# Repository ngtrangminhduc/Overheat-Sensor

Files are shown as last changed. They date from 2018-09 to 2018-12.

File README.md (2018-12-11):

# An Overheat Sensor with Raspberry Pi and HDC1008 sensor 

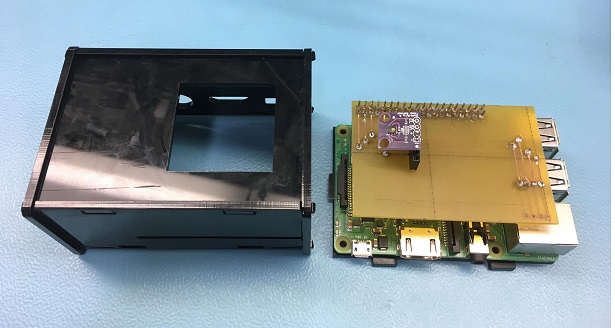
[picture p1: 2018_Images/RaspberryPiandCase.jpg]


## Table of Contents

I. [Introduction](#i-introduction)

II. [Overheat Sensor Materials](#ii-overheat-sensor-materials)

III. [Overheat Sensor Schedule](#iii-overheat-sensor-schedule)

IV. [Overheat Sensor Assembly](#iv-overheat-sensor-assembly)

V. [Overheat Sensor Power Up and Testing](#v-overheat-sensor-power-up-and-testing)

VI. [Image Creation and Enterprise Wifi](#vi-image-creation-and-enterprise-wi-fi)

VII. [Reproduction in Quantity](#vii-reproduction-in-quantity)

### I. Introduction

Raspberry Pi gets overheat easily when combined with other components, and can hardly be noticed if put inside cases. Internal hardware can be damaged if no immediate resolutions are taken.

HDC1008 is a Temperature and Humidity sensor that can solve the problem. It8 has a wide range of temperature with +-0.2 Celsius degree, making it a very accurate sensor to detect any temperature change, and to ensure a spontaneous reaction from the users. Its low power consumption and two operation modes (sleep and measurement) allow itself to fit battery / power harvesting applications.

**Note**: This sensor is now classified as **Obsolete** in most of electronic websites, due to the coming of many new upgraded sensors

The whole operation of the project can be demonstrated through this XML diagram: 

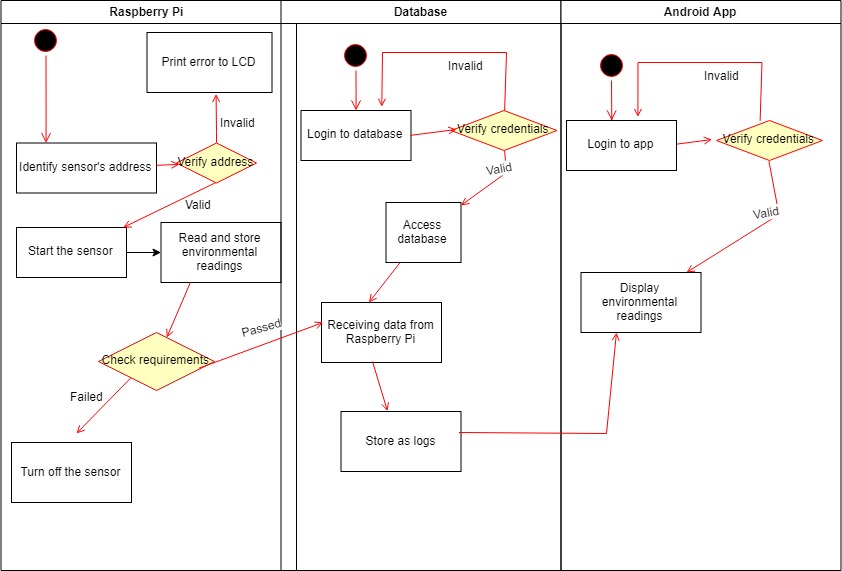
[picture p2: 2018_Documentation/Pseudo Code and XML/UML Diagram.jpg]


For convenient purposes, this documentation will focus mainly on the production of the sensor only. 

### II. Overheat Sensor Materials

The components for this project are:
- Raspberry Pi 3B+
- HDC1008 Temperature & Humidity Sensor  
- PCB
- I2C LED Screen (Optional)
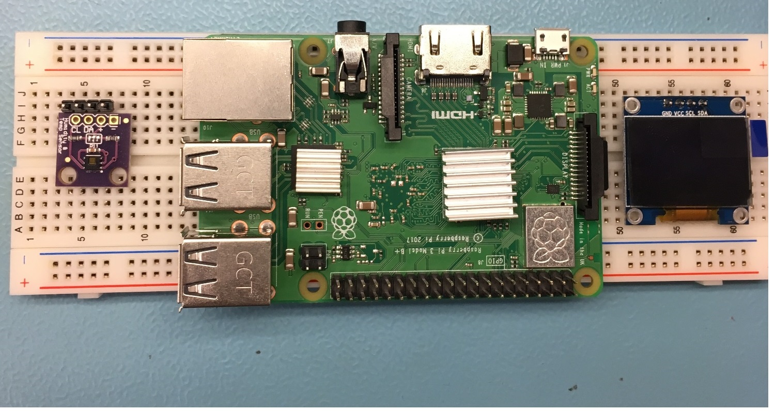
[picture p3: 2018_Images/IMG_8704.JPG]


- 6-pin headers
- 2x20-pin header

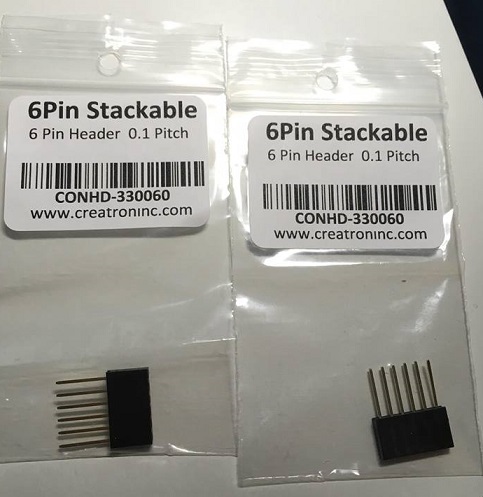
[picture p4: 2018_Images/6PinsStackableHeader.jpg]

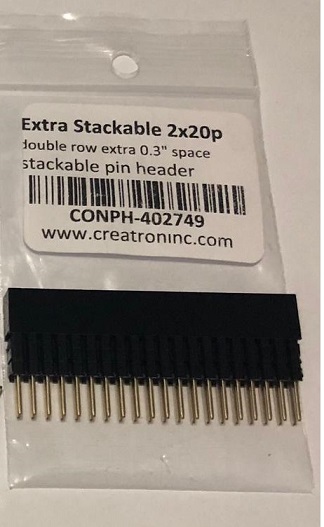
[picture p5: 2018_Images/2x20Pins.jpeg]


The softwares for this project are:
- Remote Desktop Connection / VNC Viewer
- Fritzing (for designing purposes) (can be freely used in the Lab)
- CorelDraw (for designing purposes) (can be freely used in the Lab)

Total budget for this project is approximately 190$. More details can be found in the <a href="https://raw.githubusercontent.com/ngtrangminhduc/OverheatSensor/master/2018_Documentation/Proposal%2C%20Budget%2C%20Project%20Schedule/Budget.xlsx">budget</a>.

The HDC1008 sensor should be ordered as soon as possible, as it may take up 2 weeks to 1 month due to its unpopularity

### III. Overheat Sensor Schedule
Overall, if all materials are present, then it should not take more than 3 days to build a complete, functional product. Most of the time will be spent on installing the SD card and building the case for the Raspberry Pi, while the coding is rather simple.

This is the schedule I followed for the whole semester

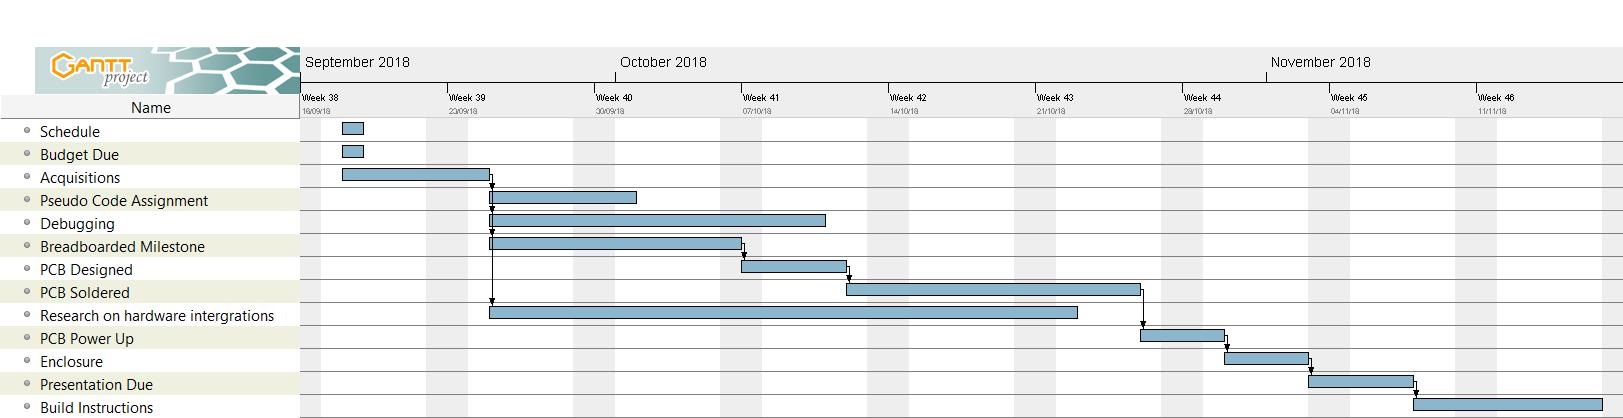
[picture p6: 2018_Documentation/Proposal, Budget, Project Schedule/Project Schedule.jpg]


### IV. Overheat Sensor Assembly

#### IV.1 Printed Circuit Board

A PCB is required to connect the Sensor to the Raspberry Pi without using jumper wires and such. The design file of PCB can be found <a href="https://raw.githubusercontent.com/ngtrangminhduc/OverheatSensor/master/2018_Documentation/Fritzing/DucNguyen_HDC1008.zip">here</a>.
This is the Breadboard view of the project:

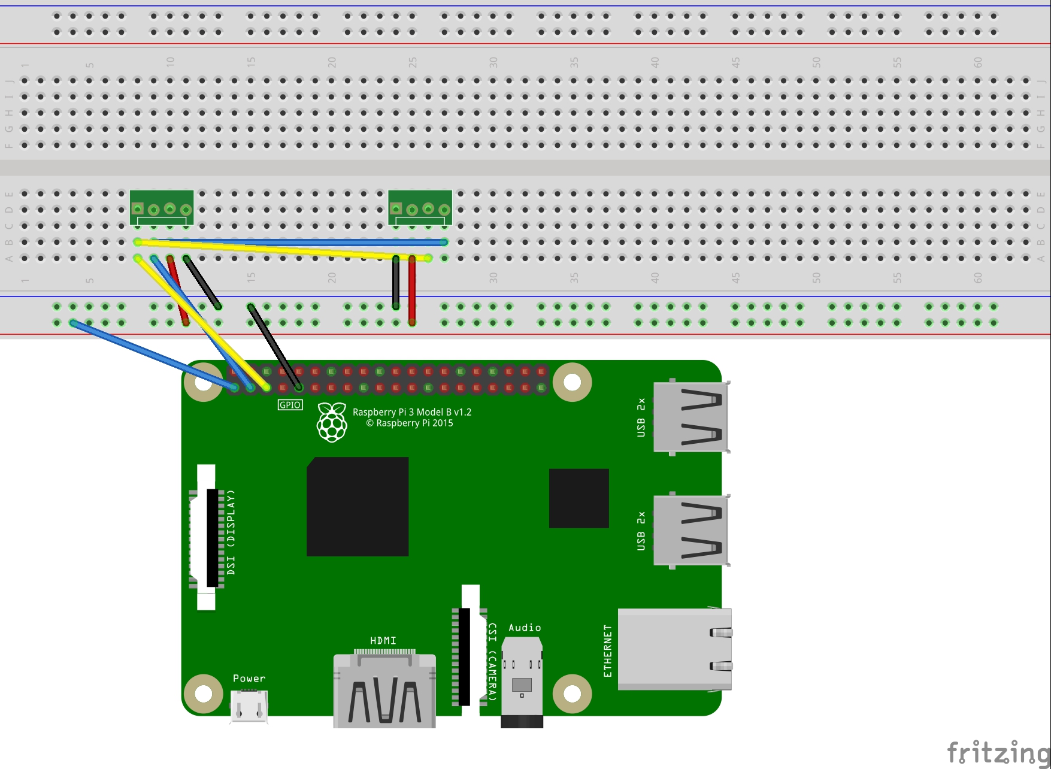
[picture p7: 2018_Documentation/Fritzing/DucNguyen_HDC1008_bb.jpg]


The PCB View was designed, based on the Breadboard View by using Fritzing.

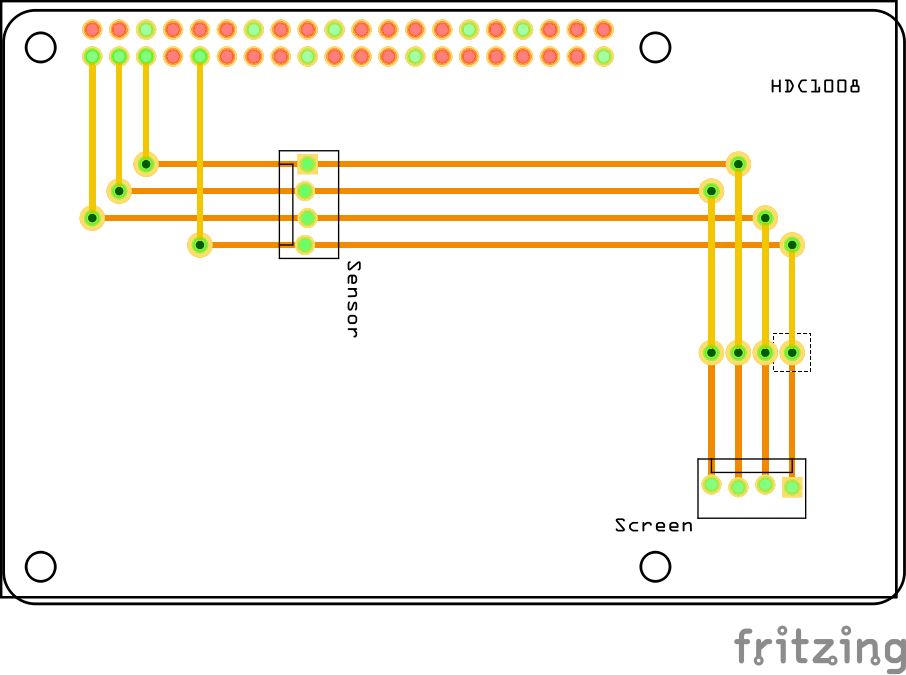
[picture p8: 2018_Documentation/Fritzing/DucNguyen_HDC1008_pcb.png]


Soldering can be done in the Lab, which may take you 30mins to 2hours, depends on how comfortable you are in soldering:

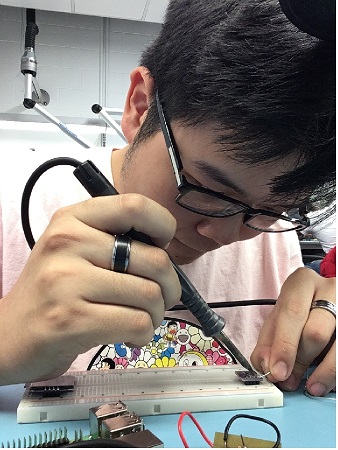
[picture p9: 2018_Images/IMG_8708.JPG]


This is the finished PCB

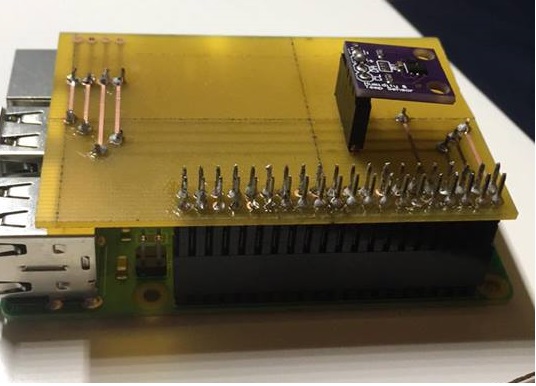
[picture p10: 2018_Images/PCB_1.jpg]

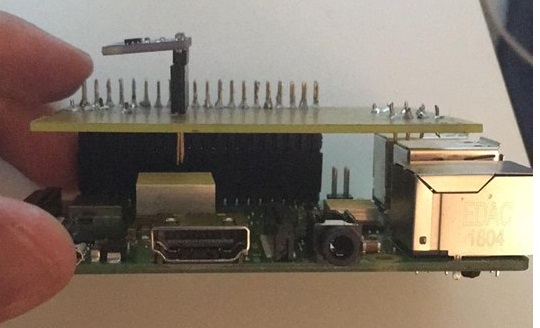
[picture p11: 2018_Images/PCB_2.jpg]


#### IV.2 Raspberry Pi Case

The design file of Raspberry Pi Case can be found in I drive --> DropBoxes --> mdrk0011 --> Pickup --> CENG317 --> Pi2CaseX7.cdr . The case should be redesigned based on the Pi's new size (when the PCB is attached) + its functionality. Kelly and Vlad in the Prototype Lab are very informative and helpful on assisting students with using CorelDraw.

My design file can be found here  <a href="https://raw.githubusercontent.com/ngtrangminhduc/OverheatSensor/master//2018_Documentation/Pi%20Case%20-%20Overheat%20Sensor.cdr">here</a>. This is a picture of the design in CorelDraw 

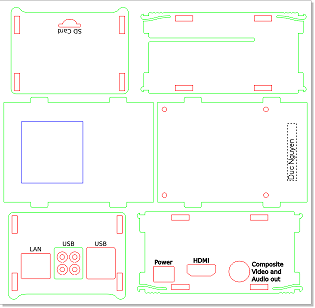
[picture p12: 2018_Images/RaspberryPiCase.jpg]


The file should be emailed to the Prototype Lab (prototypelab@humber.ca). The case will be laser cut and completed in 1-2 days time. 



This is the final product when everything's assembled together

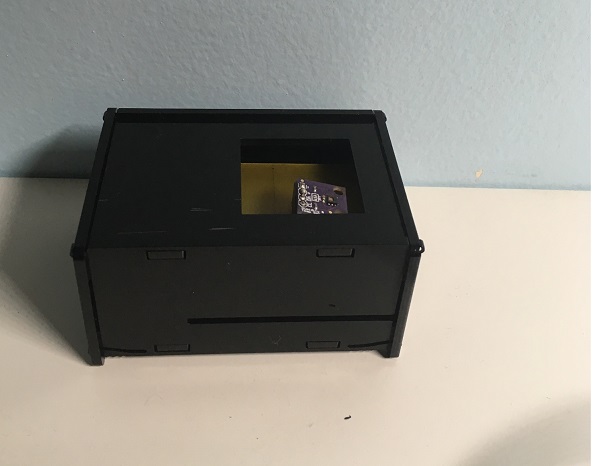
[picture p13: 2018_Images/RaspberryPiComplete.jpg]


### V. Overheat Sensor Power Up and Testing

This is the first power up time of the Overheat Sensor. Connections are properly made by looking at the pinout of the Raspberry Pi

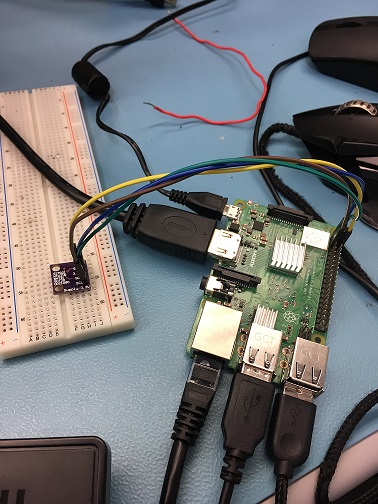
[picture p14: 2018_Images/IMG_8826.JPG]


This is the output. Temperature and Humidity are shown every 0.5s. The sensor works fine under 0x40. It can work under 0x41 or 0x42 as well if it is **manufactured by Adafruit**. The souce code can be found <a href="https://raw.githubusercontent.com/ngtrangminhduc/OverheatSensor/master//2018_SourceCode/hdc1008.py">here</a>

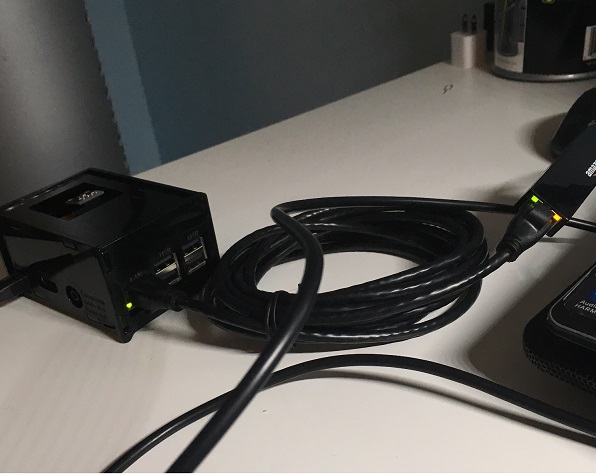
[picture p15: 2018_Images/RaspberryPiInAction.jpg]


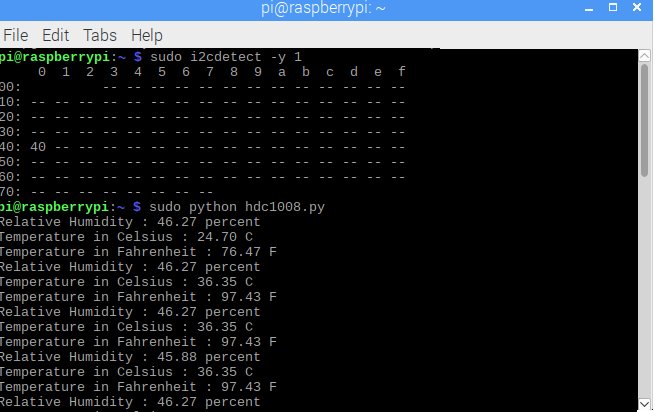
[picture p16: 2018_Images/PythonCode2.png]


### VI. Image Creation and Enterprise Wi-Fi

#### VI.1 Image Creation

1. Format an at least class 10 minimum of 8GB SD card with: https://www.sdcard.org/downloads/formatter_4/index.html With SD Card Formatter (https://www.sdcard.org/downloads/formatter_4/)

2. Download, unzip, and copy the folder contents of http://downloads.raspberrypi.org/NOOBS/images/NOOBS-2017-08-17/NOOBS_v2_4_3.zip into the SD card

3. Insert the SD Card into the Raspberry Pi. For first time usage, a HDMI cable and a separate screen is required. 

**Note: The SD Card is now readable by only the Raspberry Pi. By re-inserting the SD card back into your PC, there's a high chance of corrupting the SD card and resulting in re-installation**

4. Perform necessary update as instructed by the Pi.

5. Open the terminal in the top left corner of the screen and input the following lines (this takes quite a long time):

wget https://raw.githubusercontent.com/six0four/StudentSenseHat/master/firmware/hshcribv01.sh \  
-O /home/pi/hshcribv01.sh  
chmod u+x /home/pi/hshcribv01.sh  
/home/pi/hshcribv01.sh

**Note: If there's error running the code, you can download the script <a href="https://raw.githubusercontent.com/ngtrangminhduc/OverheatSensor/master//2018_SourceCode/hshcribv01.sh">here</a> and run it manually on your pi**

6. Reboot

#### VI.2 Enterprise Wi-Fi

It will be more convenient to connect to the Raspberry Pi through Wi-Fi. This is the instruction for connection the Raspberry Pi to the Humber Wifi:

1.  In /etc/network/interfaces:
	```
	auto lo
	iface lo inet loopback
	iface eth0 inet dhcp
	allow-hotplug wlan0
	iface wlan0 inet manual
	wpa-roam /etc/wpa_supplicant/wpa_supplicant.conf
	iface default inet dhcp
	```

2.  In /etc/wpa_supplicant/wpa_supplicant.conf:

    ```
	sudo nano /etc/wpa_supplicant/wpa_supplicant.conf
	```

    ```
	# sample network configuration for Humber College myWi-Fi
	# change text in <> to your account values (remove the < and > while doing this )
	network={
		ssid="myWi-Fi@Humber"
		key_mgmt=WPA-EAP
		auth_alg=OPEN
		eap=PEAP
		identity="<YourHCNetID>"
		password="<YourHCnetPassword>"
		phase1="peaplabel=0"
		phase2="auth=MSCHAPV2"
		priority=999
		proactive_key_caching=1
	}

	# Sample network configuration for joining Eduroam Wi-Fi network
	# change text in <> to your account values (remove the < and > while doing this )
	network={
		ssid="eduroam"
		scan_ssid=1
		key_mgmt=WPA-EAP
		eap=PEAP
		identity="<YourHCnetID>@humber.ca"
		password="<YourHCnetPassword>"
		phase1="peaplabel=0"
		phase2="auth=MSCHAPV2"
		proactive_key_caching=1

	}

	# Sample network configuration for joining a home wi-fi network.
	# change text in <> to your network values (remove the < and > while doing this )
	network={
		ssid="<yourNetworkSSID"
		psk="<yourNetworkPassword>"
		proto=RSN
		key_mgmt=WPA-PSK
		pairwise=CCMP
		auth_alg=OPEN
	}

	#Sample networtk configuration for joining open, unsecured network
	network={
		ssid="<yourNetworkSSID>"
		key_mgmt=NONE
	}
	```

3.  Download Humber Certificate (For HumberSecure).cer from https://its.humber.ca/wireless/humbersecure/

4.  Reboot

5. If you have trouble connecting the Pi through Ethernet Cable, it's best to use Advanced IP Scanner and search for the Pi's IP Address.

### VII. Reproduction in Quantity 

If this product is to be massively built, several tips can be considered:
- It's better to use NOOBS and write it to multiple SD cards, as it takes less time than flashing with Etcher.
- The source code doesn't need additional libraries, so it can be retrieved as soon as the Pi starts.
- For financial purposes, it's better to order the sensors from China, as they are cheaper and no shipping cost is required (even though it would take nearly a month to arrive)

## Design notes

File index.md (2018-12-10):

**December 09, 2018**: Finished ReadMe.md . It is displayed in the main repository.

**November 27, 2018**: Presenting my product to the whole class! Presentation can be found <a href="https://raw.githubusercontent.com/ngtrangminhduc/OverheatSensor/master/2018_Documentation/Presentations/Presentation%20-%20Nov%2027.pptx">here</a>

**November 20, 2018**: Finished designing and laser printing the Raspberry Pi Case. I will drill the screws tomorrow. The CorelDraw design can be found <a href="https://raw.githubusercontent.com/ngtrangminhduc/OverheatSensor/master/2018_Documentation/Pi%20Case%20-%20Overheat%20Sensor.cdr">here</a>




**November 14, 2018**: Demonstrated running code to professor in class. I also updated the budget. 

#Progress Report: The project has meet its requirement, functionality and budget-wise. I'm still trying to implement the screen to show the result from the sensor, as it requires more work than it seems.



**November 6, 2018**: Finished Soldering the essential parts. A LED I2C screen can still be implemented on the PCB, but I'm still testing it as it's not fully functional yet. I accidentally bought a 6-header stackable pin instead of 4, so the professor helped me turn it into a 4-header one.



After soldering




**October 30, 2018**: Finished desigining my PCB and emailed it to Prototype Lab. The file can be found <a href="https://raw.githubusercontent.com/ngtrangminhduc/OverheatSensor/master/2018_Documentation/Fritzing/DucNguyen_HDC1008.fzz">here</a>


**October 23, 2018**: Demonstrated my sensor to Kristian. The code worked, but the address was not the desired one. After researching, I know how to change the address from 0x40 to 0x42 through Adafruit, by using pinout A0 and A1 (https://learn.adafruit.com/adafruit-hdc1008-temperature-and-humidity-sensor-breakout/pinouts). However, since Adafruit has discontinued this product, I had to buy the ones without those pinouts.I tried changing the code and even used 3rd party programs, but none worked.

The sensor is working perfectly fine under 0x40.
The screen is not needed, as data can be shown on the monitor

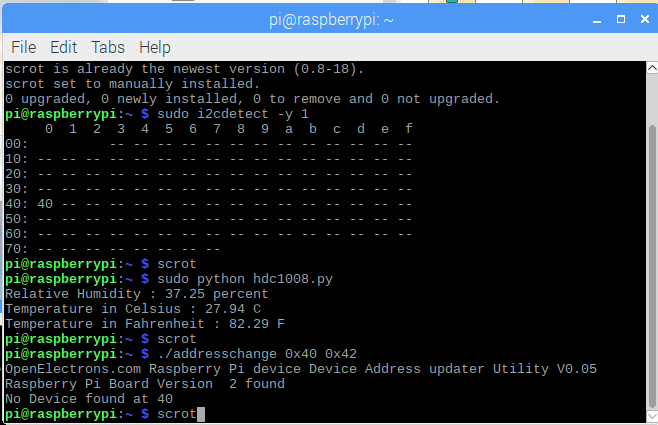
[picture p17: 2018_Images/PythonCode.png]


**October 21, 2018**: Finished the Python code.

**October 20, 2018**: Started writing the code for the sensor. I tried both Python and C and had problems with both.

**October 18, 2018**: Started the Raspberry Pi Installation. For me the NOOBS didn't work, but flashing the Raspbian ISO file into the SD card worked.

**October 16, 2018**: Showed acquisitions to Kristian, finished UML diagram and soldering



**October 12, 2018**: Discussing the Pseudo Code with partner

**October 2, 2018**: Talked to partner in Pseudo Code Assignment + Summarizing all receipts (Can be seen at 2018 Documentation --> Proof of Purchases)

**September 29, 2018** : All acquisitions delivered

**September 11, 2018** : Finish Proposal

**September 18, 2018** : Finish Schedule 

**September 25, 2018** : Finish Budget

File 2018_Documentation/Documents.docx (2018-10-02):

https://www.raspberrypi.org/forums/viewtopic.php?t=109135

https://www.hackster.io/stormy-ua/hdc1008-windows-iot-c40ed4

http://www.pibits.net/code/raspberry-pi-hdc1008-temperature-sensor.php

https://raspberrypihobbyist.blogspot.com/2015/11/hdc100x-temperaturehumidity-sensor.html

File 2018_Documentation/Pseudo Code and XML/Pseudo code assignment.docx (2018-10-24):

Pseudo Code Assignment

Third Year Student: Duc Nguyen – N01156279

First Year Student: Manpreet Parmar – N01302460

I. Pseudo Code – by Manpreet

Setup

Identify address of sensor

Verify address of sensor

If verify has an error

Print to lcd (error)

End if

Log into database

If login is invalid

Prompt user to re-enter

End if

End setup

Loop

Get Temperature and save it in Temperature

Get Humidity and save it in Humidity

Send to Pi (Temperature, Humidity)

If ( 0 < Temperature <= 80 || 0 < Humidity <=80%)

Print to lcd (Temperature°c , Humidity %)

Get current time and save it in cTime

Save in data log (Temperature, Humidity, cTime)

Send log to android app (Temperature, Humidity, cTime)

Print log on android app (Temperature, Humidity, cTime)

End if

Else if

Turn the sensor off

Give user warnings

End else if

End loop

II.UML Diagram – by Duc


III.Evaluation

Manpreet’s performance was better than I expected. He replied all emails instantly, came to every meeting on time and was very communicative overall. He was eager to start the project, and delivered the product on schedule. During the discussion of the code, Manpreet demonstrated his understanding and suggestion in a very straightforward and constructive manner. He showed how critical he can think, and how potential he can be in this field, both in ethics and this particular field.

Pseudo Code grade: 4.5/5

Overall grade: 5/5

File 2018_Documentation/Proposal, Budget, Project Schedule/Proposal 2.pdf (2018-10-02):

Submission Date | 11/09/2018
Project Name | Overheat Sensor
Student Name | Duc Nguyen
Project repository | https://github.com/ngtrangminhduc/OverheatS
| ensor
OverheatSensor choice | HDC1008 Temperature & Humidity Sensor
The database will store | Temperature scans in every 1s ; Timestamps

The mobile device functionality
will include | The option to stop the device if it's overheating
I will be collaborating with the
following company/department Humber College - School of Applied Technology
My group in the winter semester will include | Abiodun's PWM driver and Aldious's ToF
| distance, to create a RC car

50 word problem statement

RC car created by Raspberry Pi can overheat without being noticed, and can create damage to the internal hardwares.

100 words of background

HDC1008 has a wide range of temperature with +-0.2 Celsius degree, making it a very accurate sensor to detect any temperature change, and to ensure a spontaneous reaction from the users. Its low power consumption and two operation modes (sleep and measurement) allow itself to fit battery / power harvesting applications.

Current product APA citation

HDC1008 Low Power, High Accuracy Digital Humidity Sensor with Temperature Sensor [PDF]. (2014, October). Texas Instrument. (http://www.ti.com/lit/ds/symlink/hdc1008.pdf)

Existing research IEEE paper APA citation

Temperature and Humidity Detection System of Communication System Based on Raspberry Pi -IEEE Conference Publication. (2018, April 9). Retrieved from
https://ieeexplore.ieee.org/document/8332746/

Brief description of planned purchases

Raspberry Pi 3+ B ($99.99) ; HDC 1008 Temperature & Humidity Sensor ($6.98)

Solution description

Attach the sensor to the RC car, and use the Raspberry Pi to send out data usage to the mobile and database. If the temperature surpasses the limit, the car will receive a signal to shutdown

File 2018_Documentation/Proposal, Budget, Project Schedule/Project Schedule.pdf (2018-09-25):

CENG317 | 18-Sep-2018
| http://

# Project manager

Project dates | 18-Sep-2018 - 27-Apr-2019
Completion | 0%
Tasks | 23
Resources | 0

Name Group Meetings and Updates Schedule Budget Due Acquisitions Pseudo Code Assignment Debugging Breadboarded Milestone PCB Designed PCB Soldered Research on hardware integrations PCB Power Up Enclosure Presentation Due Build Instructions App, Web and Database Requirement Project Outline and Proposal Hardware, Software, Database Development Overall Test 1 Overall Test 2 Group Integration Group Troubleshooting Project Demonstration Group Presentation

CENG317 | 18-Sep-2018
Tasks | 2

# Gantt Chart

3

# Name

# Group Meetings and Updates

# Schedule

# Budget Due

# Acquisitions

# Pseudo Code Assignment

# Debugging

# Breadboarded Milestone

# PCB Designed

# PCB Soldered

# Research on hardware integrations

# PCB Power Up

# Enclosure

# Presentation Due

# Build Instructions

# App, Web and Database Requirement

# Project Outline and Proposal

Hardware, Software, Database Developm...

# Overall Test 1

# Overall Test 2

# Group Integration

# Group Troubleshooting

# Project Demonstration

# Group Presentation

2018 | 2019
Week 41 | Week 42 | Week 43 | Week 44 | Week 45 | Week 46 | Week 47 | Week 48 | Week 49 | Week 50 | Week 51 | Week 52 | Week 1 | Week 2 | Week 3 | Week 4 | Week 5 | Week 6 | Week 7 | Week 8 | Week 9 | Week 10 | Week 11 | Week 12 | Week 13 | Week 14 | Week 15 | Week 16 | Week 17 | Week 18
07/10/18 | 14/10/18 | 21/10/18 | 28/10/18 | 04/11/18 | 11/11/18 | 18/11/18 | 25/11/18 | 02/12/18 | 09/12/18 | 16/12/18 | 23/12/18 | 30/12/18 | 06/01/19 | 13/01/19 | 20/01/19 | 27/01/19 | 03/02/19 | 10/02/19 | 17/02/19 | 24/02/19 | 03/03/19 | 10/03/19 | 17/03/19 | 24/03/19 | 31/03/19 | 07/04/19 | 14/04/19 | 21/04/19 | 28/04/19

# Resources Chart

4

Name | Default role
Week 41 | Week 42 | Week 43 | Week 44 | Week 45 | Week 46 | Week 47 | Week 48 | Week 49 | Week 50 | Week 51 | Week 52 | Week 1 | Week 2 | Week 3 | Week 4 | Week 5 | Week 6 | Week 7 | Week 8 | Week 9 | Week 10 | Week 11 | Week 12 | Week 13 | Week 14 | Week 15 | Week 16 | Week 17 | Week 18
07/10/18 | 14/10/18 | 21/10/18 | 28/10/18 | 04/11/18 | 11/11/18 | 18/11/18 | 25/11/18 | 02/12/18 | 09/12/18 | 16/12/18 | 23/12/18 | 30/12/18 | 06/01/19 | 13/01/19 | 20/01/19 | 27/01/19 | 03/02/19 | 10/02/19 | 17/02/19 | 24/02/19 | 03/03/19 | 10/03/19 | 17/03/19 | 24/03/19 | 31/03/19 | 07/04/19 | 14/04/19 | 21/04/19 | 28/04/19

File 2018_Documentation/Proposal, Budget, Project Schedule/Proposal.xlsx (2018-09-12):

Submission Date | 2018-09-11
Project Name | Overheat Sensor
Student Name | Duc Nguyen
Project repository | https://github.com/ngtrangminhduc/OverheatSensor
OverheatSensor choice | HDC1008 Temperature & Humidity Sensor
The database will store | Temperature scans in every 1s Timestamps
The mobile device functionality will include | The option to stop the device if it's overheating
I will be collaborating with the following company/department | HaulerAds Inc
My group in the winter semester will include | Abiodun Ojo and Aldous Mendoza
50 word problem statement | Raspberry Pi gets overheat easily when combined with other components, and can hardly be noticed if put inside cases. Internal hardware can be damaged as well.
100 words of background | HDC1008 has a wide range of temperature with +-0.2 Celsius degree, making it a very accurate sensor to detect any temperature change, and to ensure a spontaneous reaction from the users. Its low power consumption and two operation modes (sleep and measurement) allow itself to fit battery / power harvesting applications.
Current product APA citation | HDC1008 Low Power, High Accuracy Digital Humidity Sensor with Temperature Sensor [PDF]. (2014, October). Texas Instrument. (http://www.ti.com/lit/ds/symlink/hdc1008.pdf)
Existing research IEEE paper APA citation | Temperature and Humidity Detection System of Communication System Based on Raspberry Pi - IEEE Conference Publication. (2018, April 9). Retrieved from https://ieeexplore.ieee.org/document/8332746/ Sudo Pi Cooler / Heater: Raspberry Pi to design an adaptive temperature sensor - IEEE Conference Publication. (2014, November 10). Retrieved from https://ieeexplore.ieee.org/document/6950711/
Brief description of planned purchases | Raspberry Pi 3+ B ($99.99) HDC 1008 Temperature & Humidity Sensor ($6.98)
Solution description | Attach the sensor to the Raspberry Pi, and use it to send out data usage to the mobile and database. If the temperature surpasses the limit, the product will receive a signal to shutdown.

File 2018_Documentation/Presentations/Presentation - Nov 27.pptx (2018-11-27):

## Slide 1

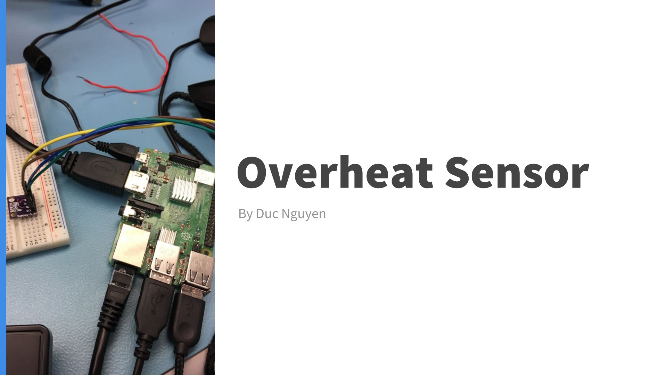
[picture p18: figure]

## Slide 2

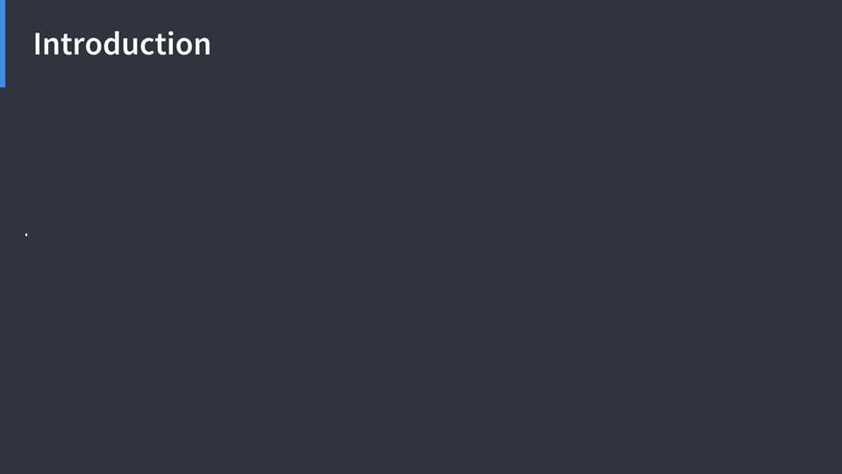
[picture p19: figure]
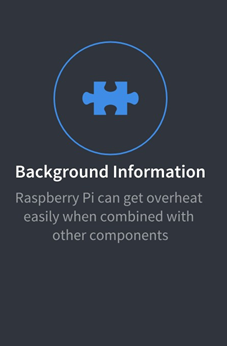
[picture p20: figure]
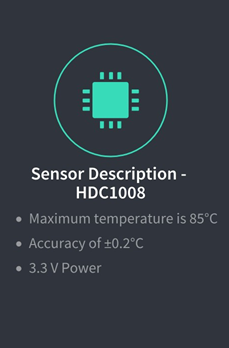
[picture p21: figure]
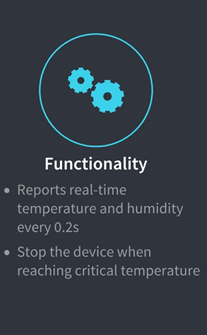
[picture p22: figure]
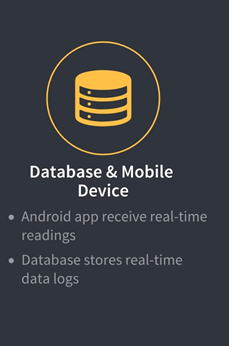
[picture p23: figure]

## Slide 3

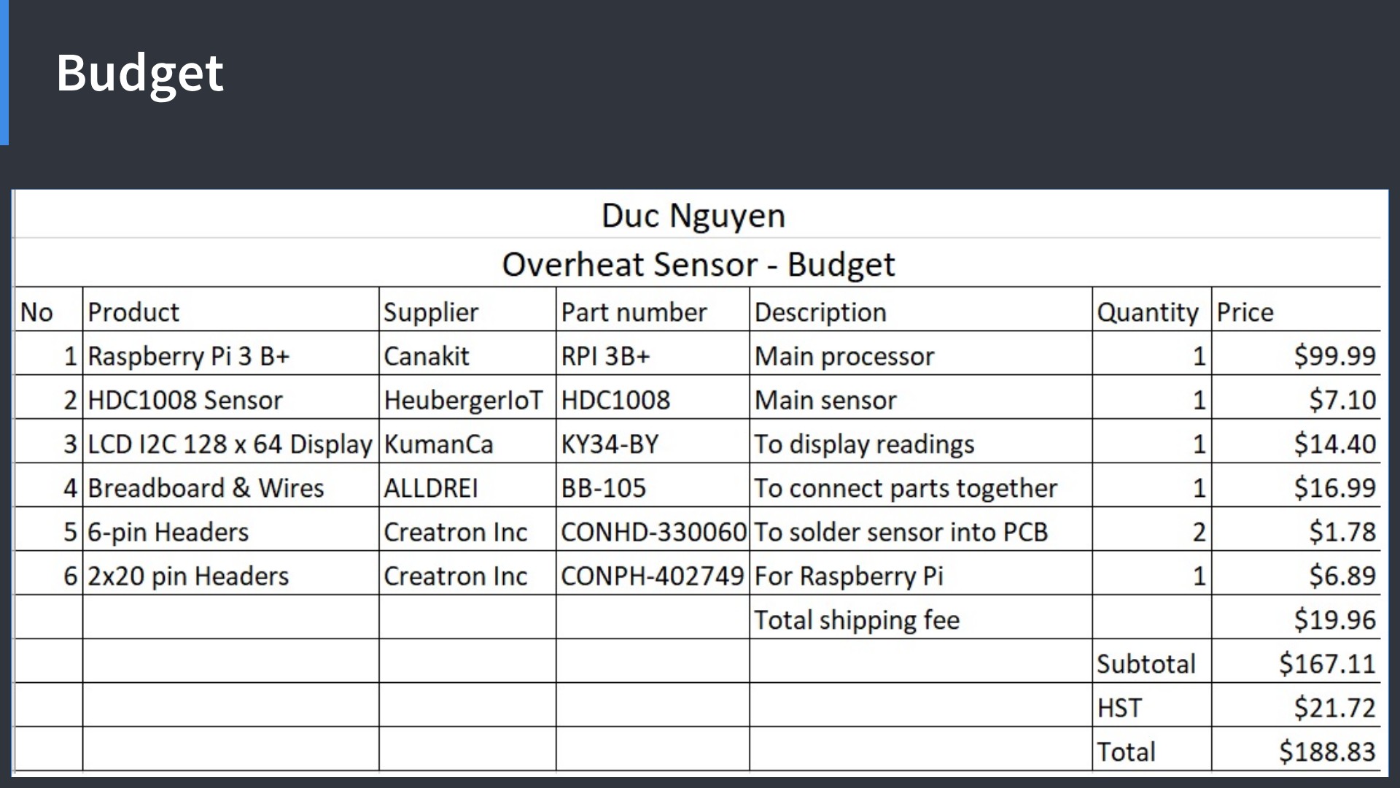
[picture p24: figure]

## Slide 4

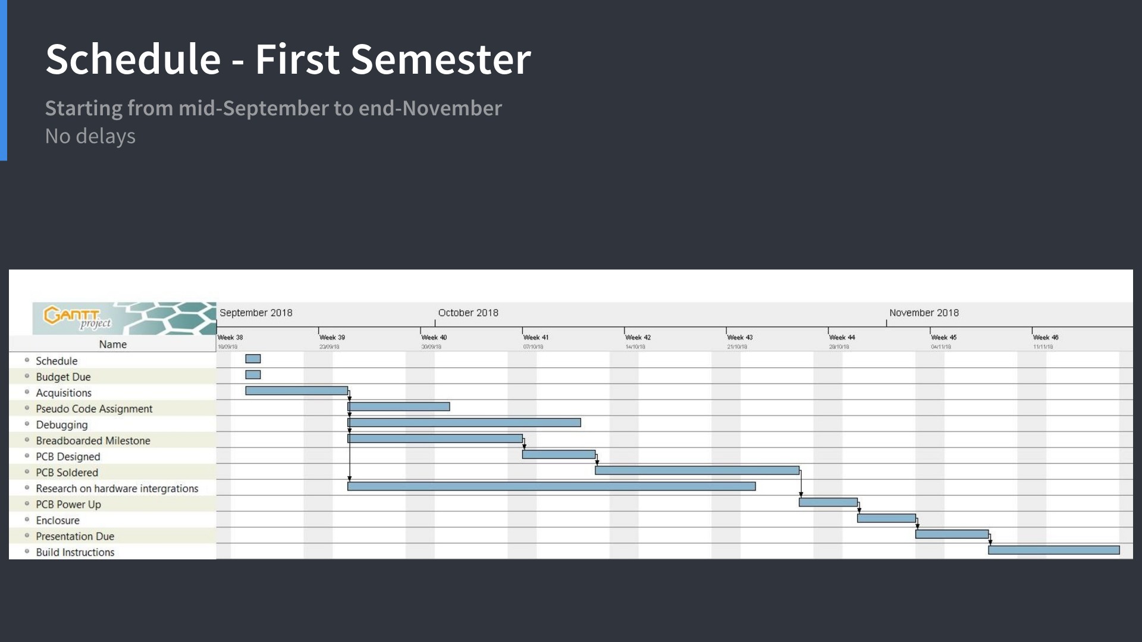
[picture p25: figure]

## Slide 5

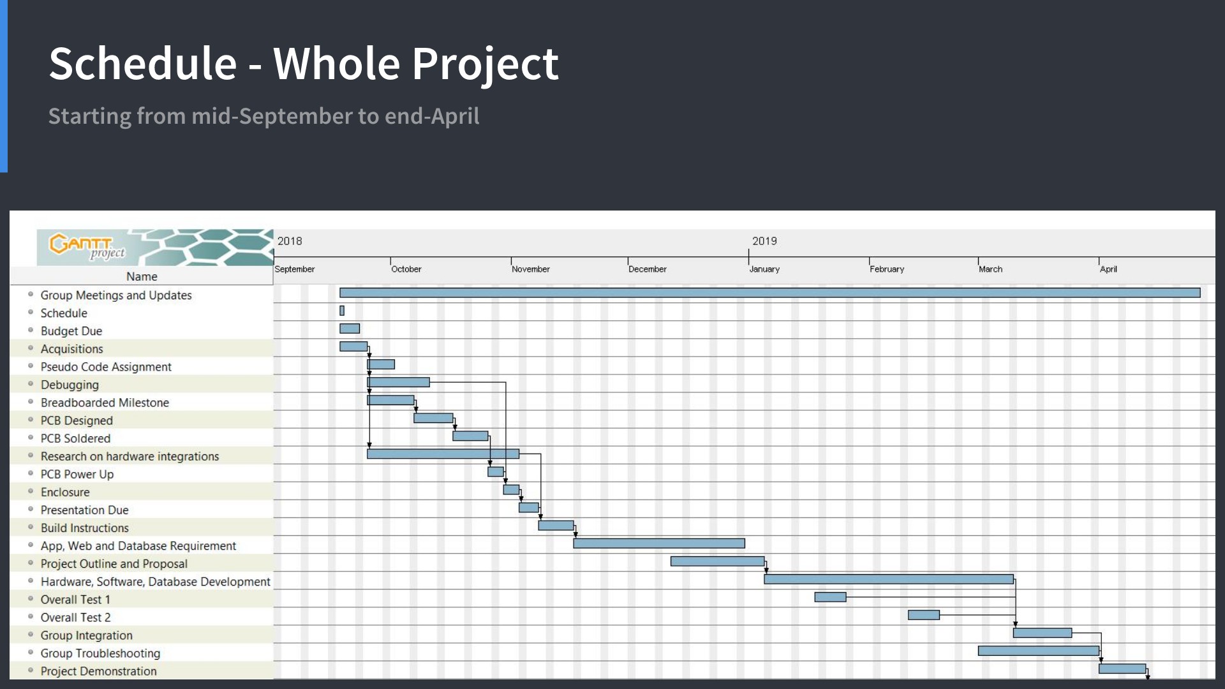
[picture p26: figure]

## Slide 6

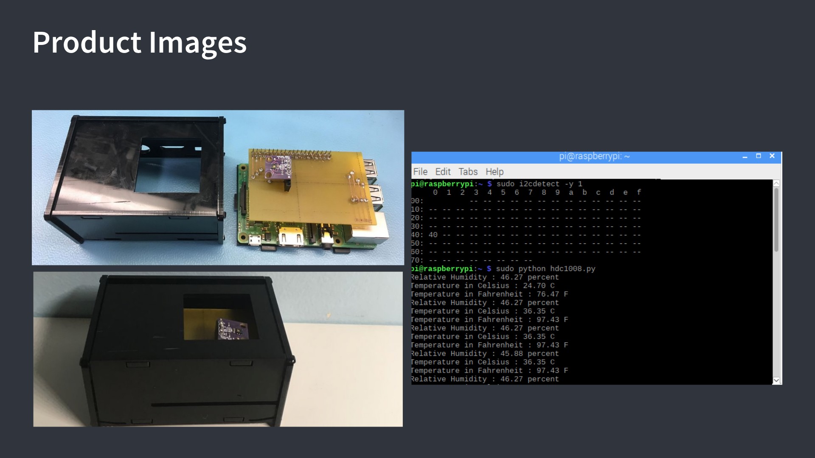
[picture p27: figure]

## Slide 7

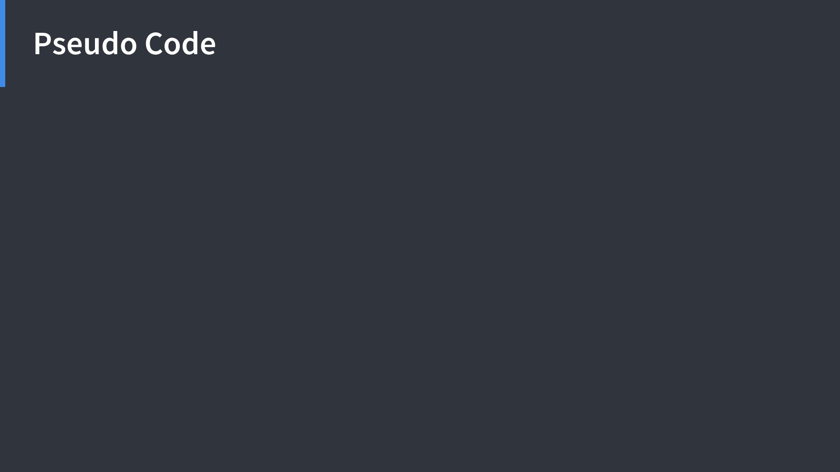
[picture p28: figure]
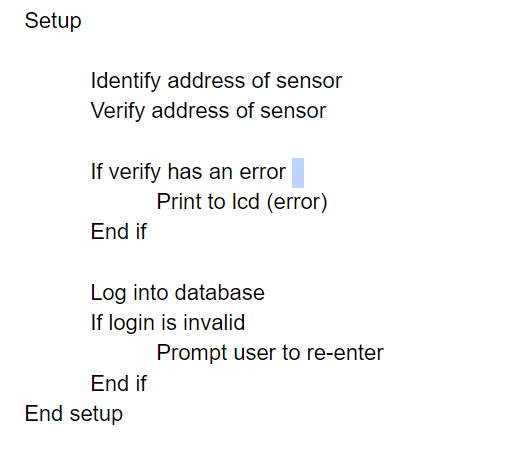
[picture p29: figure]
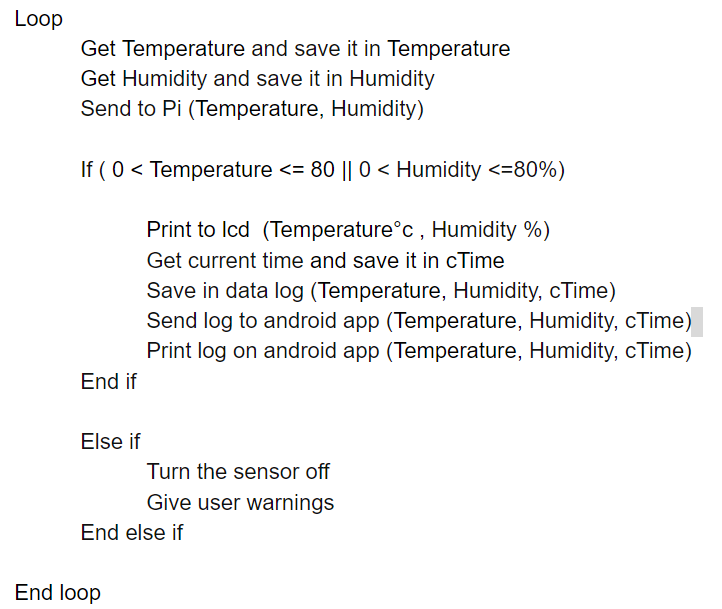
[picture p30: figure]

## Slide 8

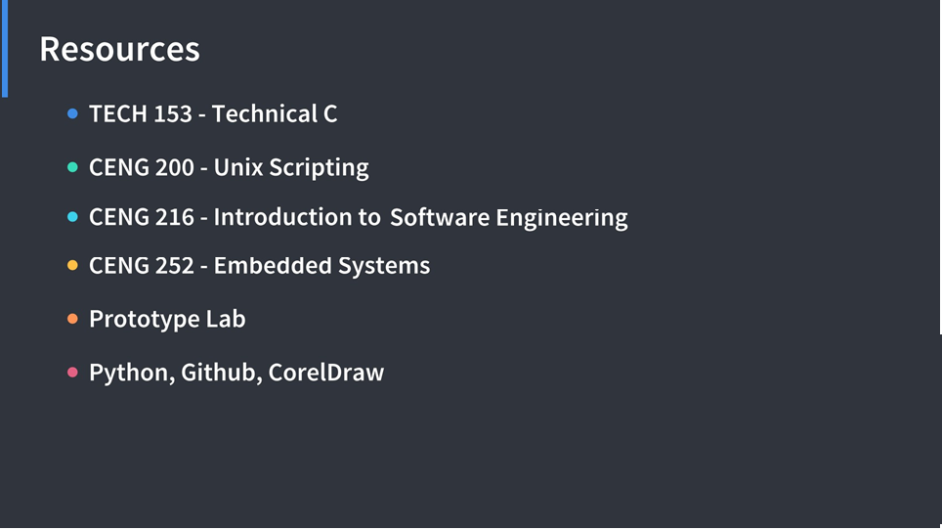
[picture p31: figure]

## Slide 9

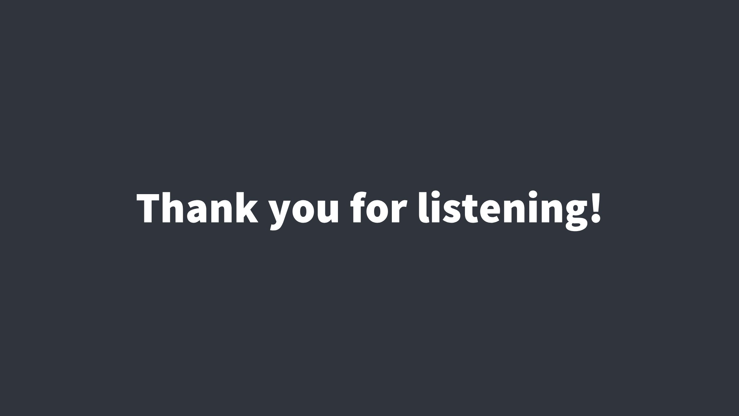
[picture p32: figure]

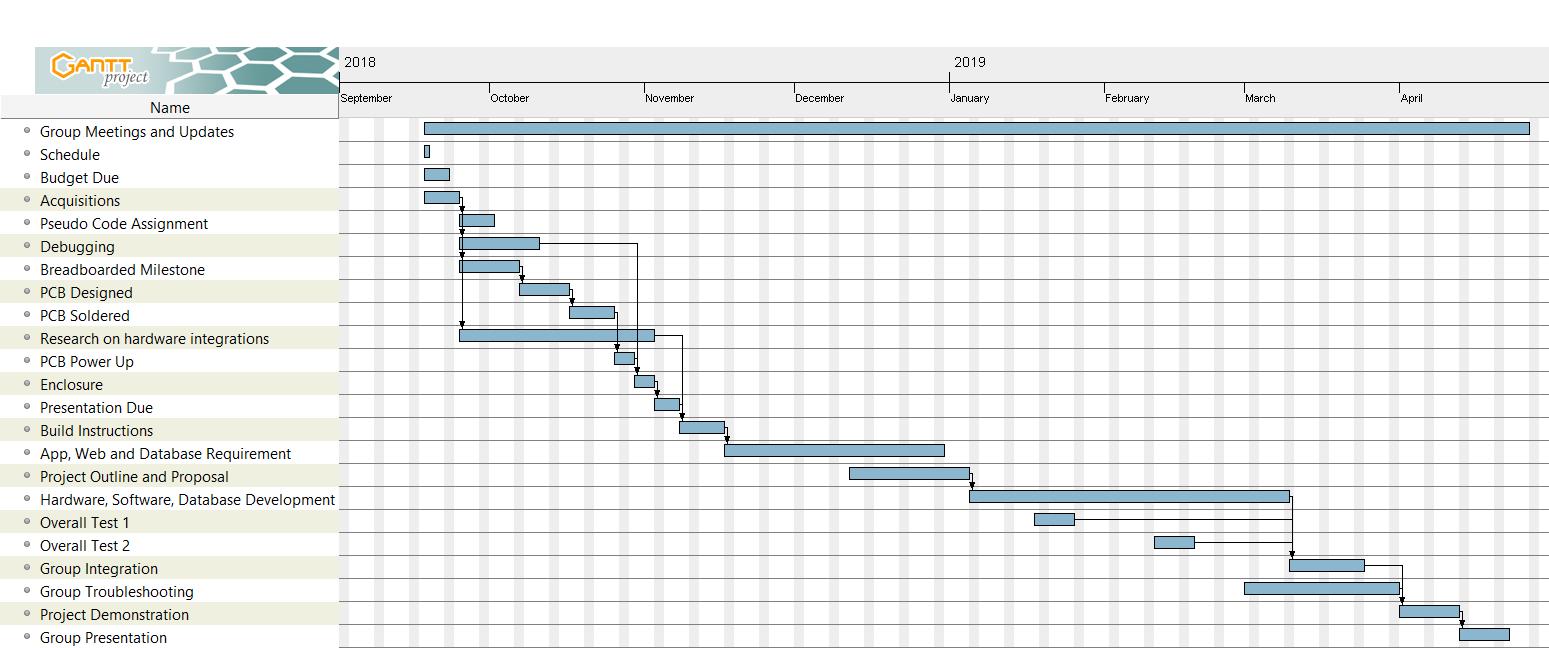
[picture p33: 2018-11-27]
2018_Documentation/Proposal, Budget, Project Schedule/Whole Project.jpg

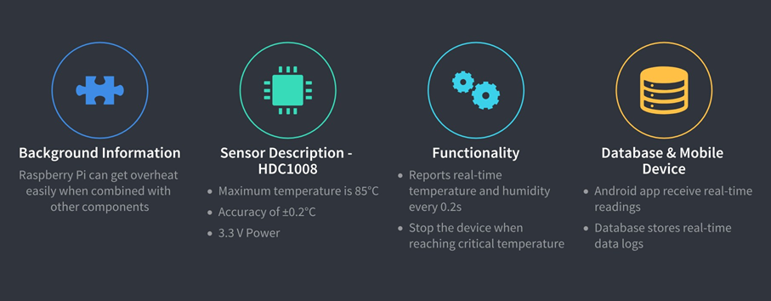
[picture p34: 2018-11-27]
2018_Documentation/Presentations/Functionalities.png

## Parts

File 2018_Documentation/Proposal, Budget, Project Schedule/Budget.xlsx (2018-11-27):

Duc Nguyen
Overheat Sensor - Budget
No | Product | Supplier | Part number | Description | Quantity | Price
1 | Raspberry Pi 3 B+ | Canakit | RPI 3B+ | Main processor | 1 | $99.99
2 | HDC1008 Sensor | HeubergerIoT | HDC1008 | Main sensor | 1 | $7.10
3 | LCD I2C 128 x 64 Display | KumanCa | KY34-BY | To display readings | 1 | $14.40
4 | Breadboard & Wires | ALLDREI | BB-105 | To connect parts together | 1 | $16.99
5 | 6-pin Headers | Creatron Inc | CONHD-330060 | To solder sensor into PCB | 2 | $1.78
6 | 2x20 pin Headers | Creatron Inc | CONPH-402749 | For Raspberry Pi | 1 | $6.89
 |  |  |  | Total shipping fee |  | $19.96
 |  |  |  |  | Subtotal | $167.11
 |  |  |  |  | HST | $21.72
 |  |  |  |  | Total | $188.83
 | Note:
 | Budget should not surpass $250

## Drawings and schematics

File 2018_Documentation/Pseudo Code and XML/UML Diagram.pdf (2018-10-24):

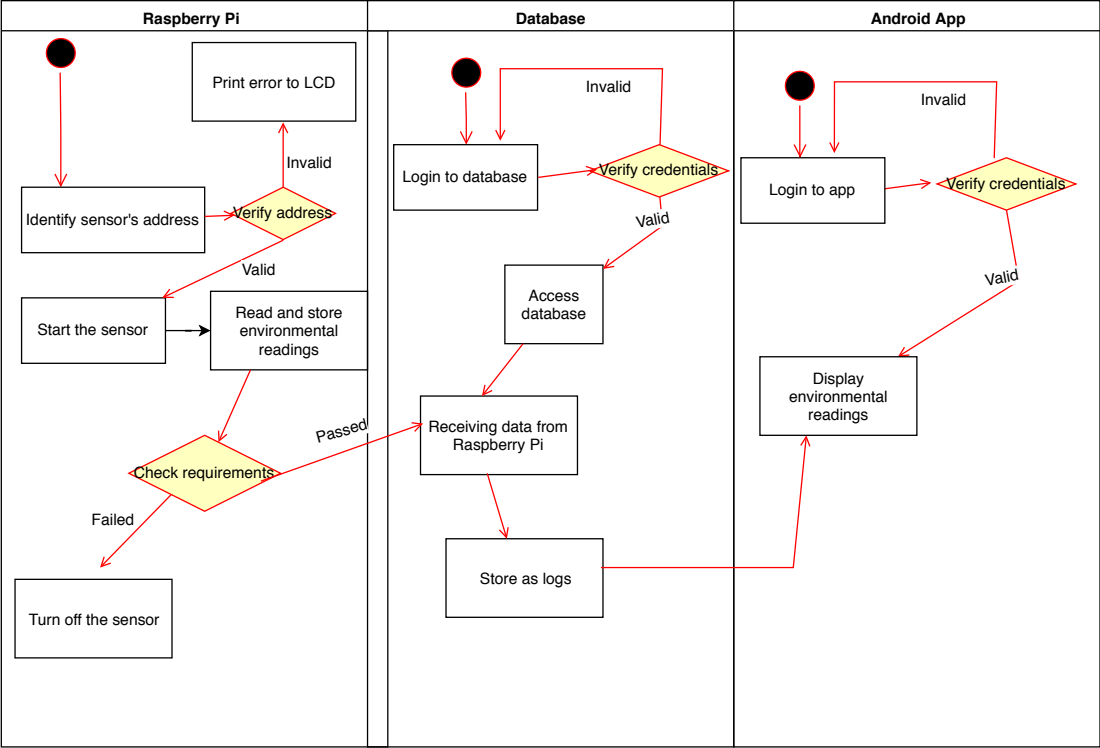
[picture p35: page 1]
Raspberry Pi; Valid; Verify address; Invalid; Check requirements; Failed; Database; Login to database; Verify credentials; Access database; Android App; Login to app; Display environmental readings Passed

Print error to LCD

Identify sensor's address

Read and store
environmental
readings

Start the sensor

Receiving data from
Raspberry Pi

Store as logs

Turn off the sensor

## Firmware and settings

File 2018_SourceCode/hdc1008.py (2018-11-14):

import smbus
import time

#Get I2C bus
bus = smbus.SMBus(1)

#HDC1000 address, 0x42
bus.write_byte_data(0x40, 0x02, 0x42)
#bus.write_byte_data(0x40, 0x02, 0x42)
#Send temp measurement command
bus.write_byte(0x40, 0x00)
time.sleep(0.5)
while True:
#Read temp data
	data0 = bus.read_byte(0x40)
	data1 = bus.read_byte(0x40)

#Convert the data
	temp = (data0 * 256) + data1
	celsTemp = (temp / 65536.0)  * 165.0 - 40
	fahrTemp = celsTemp * 1.8 +32

#Send humidity measurement command
	bus.write_byte(0x40, 0x01)
	time.sleep(0.5)

#Read humidity data
	data0 = bus.read_byte(0x40)
	data1 = bus.read_byte(0x40)

#Convert the data
	humidity = (data0 * 256) + data1
	humidity = (humidity / 65536.0) * 100.0

#Output data

	print "Relative Humidity : %.2f percent" %humidity
	print "Temperature in Celsius : %.2f C" %celsTemp
	print "Temperature in Fahrenheit : %.2f F" %fahrTemp
	time.sleep(1.0)

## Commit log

2018-09-12 Clone SSH
    [BreakoutSelection.fzz, HSHV4-student version.brd, HSHV4-student version.sch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]
2018-09-12 Adding proposal
    [Proposal.xlsx, ProposalContentStudentNameRev02.xlsx]
2018-10-02 Necessary Documentations until week 4
    [Budget.xlsx, Proposal.xlsx]
2018-10-24 Folder name changes
    [Budget.xlsx, Proposal.xlsx]
2018-10-24 Inserting Pictures
    More current info at index.md
2018-10-29 Adding fritzing files
    [Fritzing_4HeaderPin.fzz, Fritzing_RealHDC1008.fzz]
2018-10-31 Adding fritzing and gerber file
    All can be found at Fritzing folder
    [DucNguyen_HDC1008.fzz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]
2018-10-31 Cleaning up a bit
    Put files into folders
    [Budget.xlsx, Proposal.xlsx]
2018-10-31 adding PCB image
2018-11-07 PCB Images
2018-11-07 Update soldering PCB
2018-11-07 Update picture of PCB
2018-11-07 Update fritzing and PCB image
2018-11-07 update PCB picture
2018-11-14 Add source code, edit budget
    [Budget.xlsx]
2018-11-19 Deleting old SSH files
    [BreakoutSelection.fzz, HSHV4-student version.brd, HSHV4-student version.sch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]
2018-11-20 Create Pi Case - Overheat Sensor.cdr
2018-11-21 Create Raspberry Pi and Case.jpg
2018-11-27 Necessary Stuff for Presentation
    [Budget.xlsx]
2018-12-09 Finish Materials
